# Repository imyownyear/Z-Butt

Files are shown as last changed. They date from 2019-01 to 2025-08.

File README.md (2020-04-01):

Licensed under: [Attribution-NonCommercial-ShareAlike 4.0 International (CC BY-NC-SA 4.0)](https://creativecommons.org/licenses/by-nc-sa/4.0/)

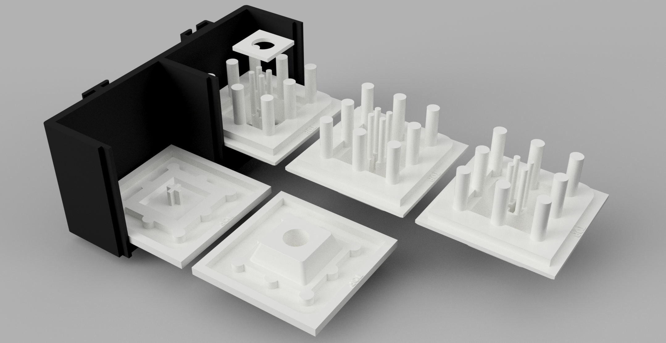
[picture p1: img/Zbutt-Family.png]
Z-Butt-1U Family


# Z-Butt
## An Artisan keycap creation platform.

If you have any questions, please contact me at:

Discord: Zappycobra#0001

[Discord Server ](https://discord.gg/nUsyadp)

Reddit: /u/imyownyear

Special thanks to yatara-cc, Fiscal_rascal, Cardiactuna, Davness<?>, CorruptedCaps, and morrae for helping with testing, providing resources, and feedback.

Please see the [Wiki](https://github.com/imyownyear/Z-Butt/wiki) for how to use, print, and make keycaps using ZButt.

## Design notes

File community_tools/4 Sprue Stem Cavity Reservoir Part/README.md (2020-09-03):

### Created by: deag
## Tool name: 4 Sprue Stem Cavity Reservoir Part
For use with:4 Sprue Stem Cavity

Sizing: 1U

Description:Pour silicone into stem cavity part 3/4 of the way up the sprue, attach the reservoir insert onto sprues. If needed, pour more silicone around insert for higher reservoir walls

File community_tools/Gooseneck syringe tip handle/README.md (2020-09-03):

### Created by: Dusty Caps
## Tool name: Gooseneck syringe tip handle
For use with: Luer slip tip syringe tips.

Sizing: NA

Description: A handle designed to be printed with an FDM printer, the tip is sized to accept luer slip tip syringe tips.

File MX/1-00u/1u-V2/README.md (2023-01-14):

Licensed under: [Attribution-NonCommercial-ShareAlike 4.0 International (CC BY-NC-SA 4.0)](https://creativecommons.org/licenses/by-nc-sa/4.0/)

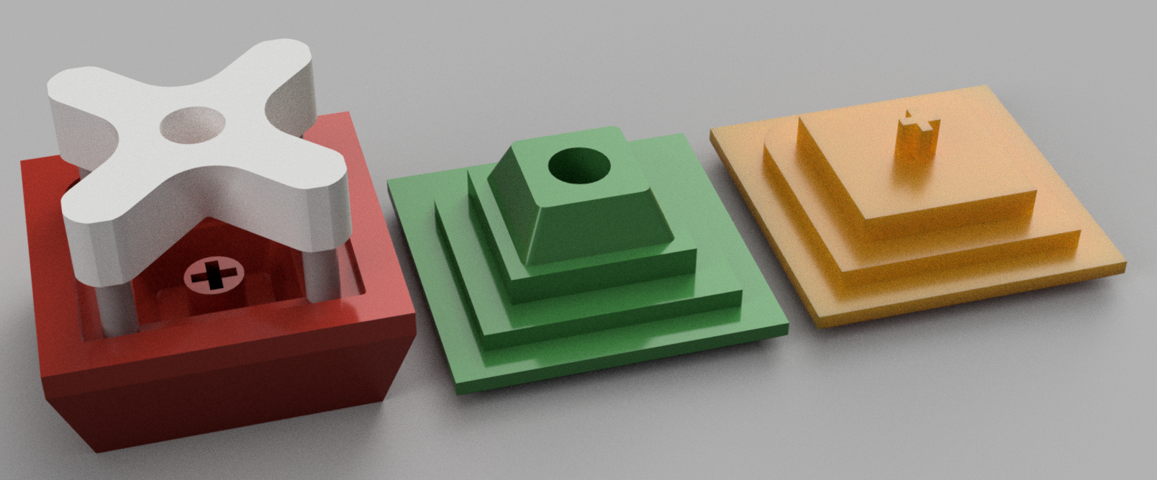
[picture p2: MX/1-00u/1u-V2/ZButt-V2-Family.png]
ZButt-1U V2 Family


# Z-Butt V2
## An Artisan keycap creation platform.

Please use 3mm Rods/Dowels with this version of Zbutt as the Sprues.

You can also glue on 5mmx1mm disc magnets to the bottom of the Master and Sculpting bases to use in combination with the Sculpting Helper.

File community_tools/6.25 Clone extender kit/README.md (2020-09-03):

### Created by: gooberpsycho
## Tool name: 6.25 Clone Riser Cavity
For use with:No Hassle Base or Lego 

Sizing: 6.25U

Description:Use in conjunction with two clone NoHassle's, one 6.25 Clone Extender, 
and one 6.25 Stem cavity in order to clone the 6.25 Stem Cavity in resin. Assemble the Clone No Hassle ends with the Clone Extender,
forming a box. Place Clone riser inside box, flush with bottom. Finally, place 6.25 stem cavity in box, on top of clone riser, 
flush with the riser's sides. Recommend placing clay inside riser to hold Stem Cavity in place so it doesn't move when pouring silicone. 
Pour enough silicone to completely cover stem cavity and allow to fully cure. You can then cast a new 6.25U Stem cavity out of resin.

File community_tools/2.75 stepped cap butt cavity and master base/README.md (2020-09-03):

### Created by: gooberpsycho
## Tool name: Stepped Caps Stem Cavity
For use with:No Hassle Base or Lego

Sizing:2.75u

Description:Use as normal 2.75U Stem Cavity. Two No Hassle Base end pieces, one No Hassle Extender 2 are needed.
Form a box using the No Hassle Base and Extender 2, then place Stepped Caps Stem Cavity into box, flush against bottom of box.
Pour Silicone in same manner as any other Stem Cavity, leaving a few millimeters of the sprues visible above the surface of the silicone. Used in conjunction with the Stepped Caps Master Base, Stepped Caps Lock key will be created.

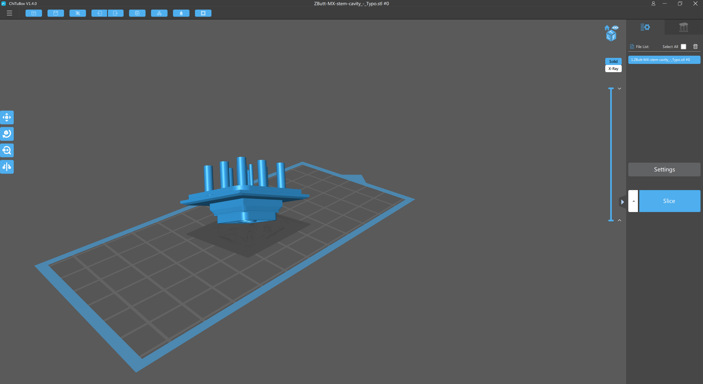
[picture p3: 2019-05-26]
img/angled-on-x-butt.png

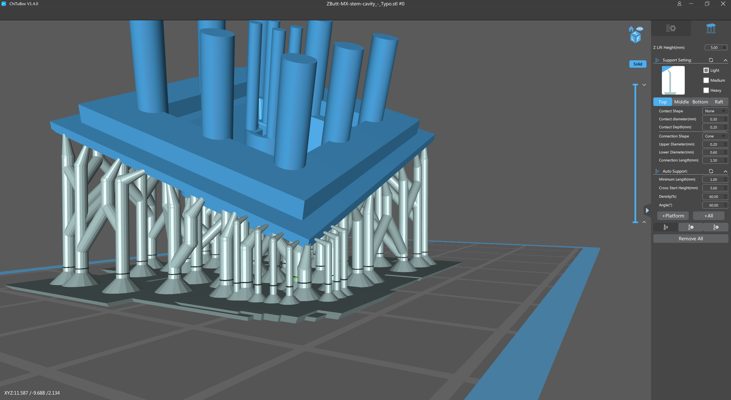
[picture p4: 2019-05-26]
img/light-support-reinforce-butt.png

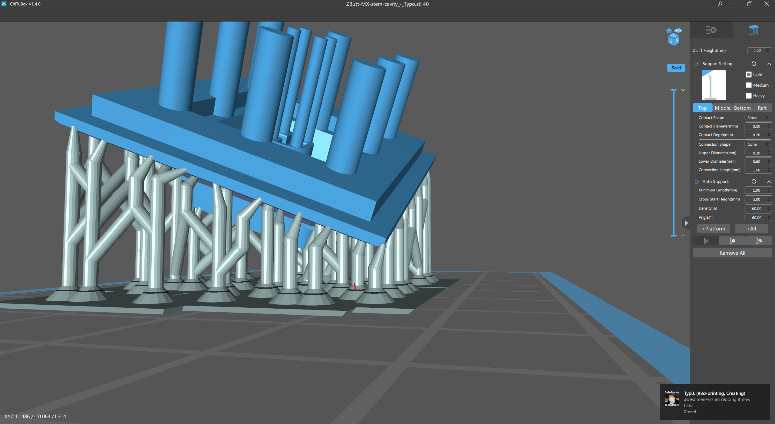
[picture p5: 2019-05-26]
img/heavy-supports-butt.png

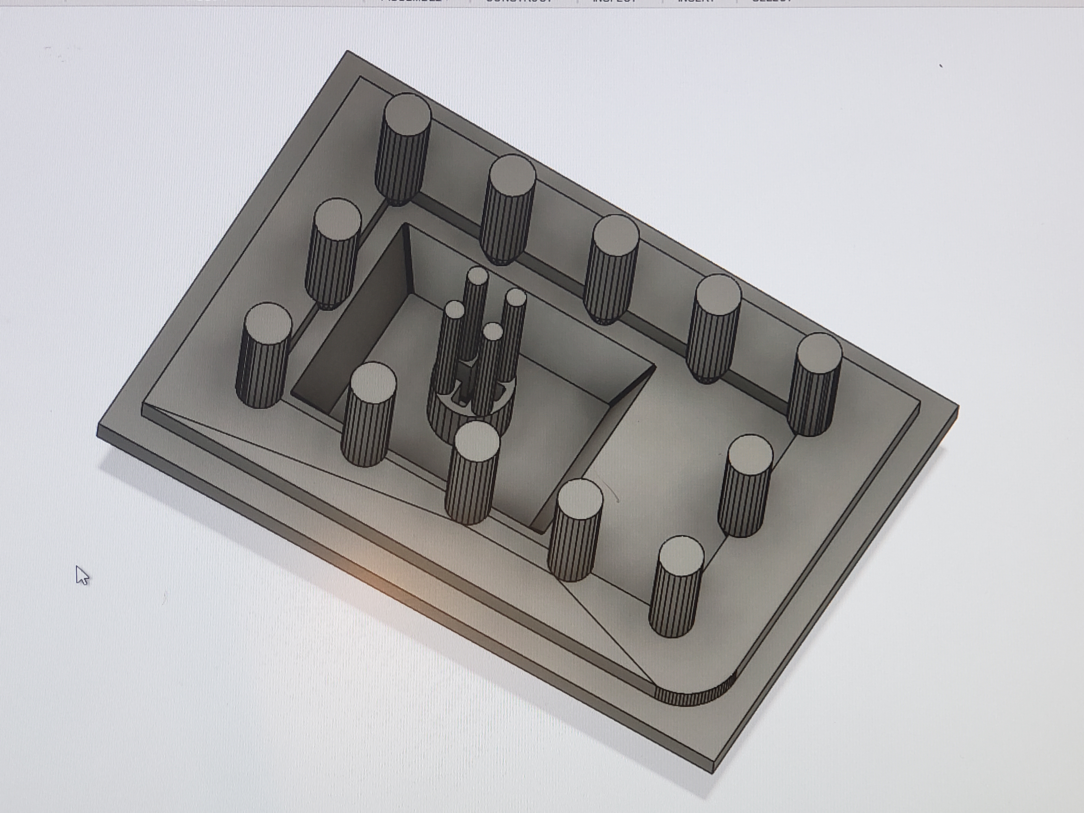
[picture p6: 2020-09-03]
community_tools/2.75 stepped cap butt cavity and master base/20200730_200228 - Robert Maynard.jpg

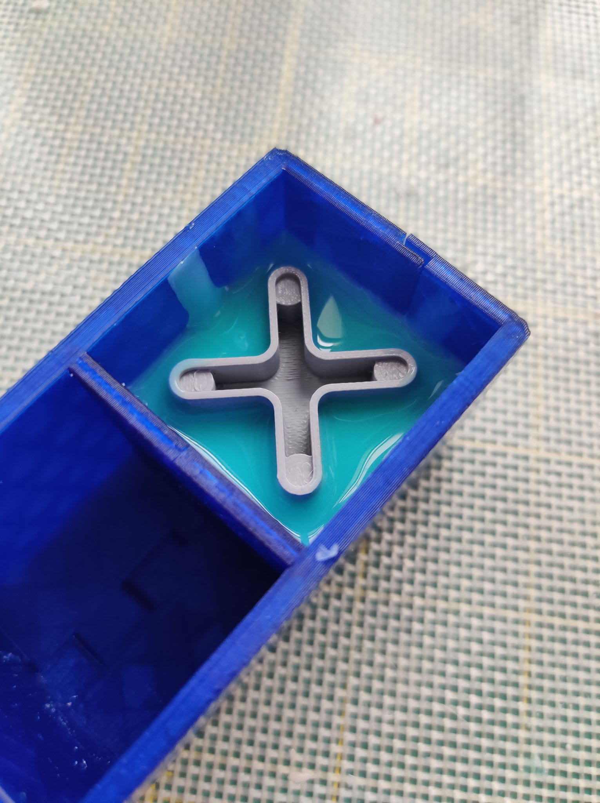
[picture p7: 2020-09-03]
community_tools/4 Sprue Stem Cavity Reservoir Part/118154245_2524324694526478_4820017302277932408_n - deagcaps.jpg

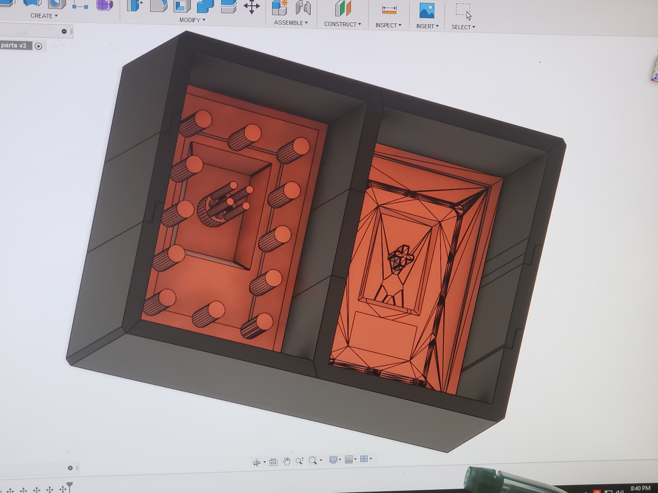
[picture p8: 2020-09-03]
community_tools/2.75 stepped cap butt cavity and master base/20200730_204056 - Robert Maynard.jpg

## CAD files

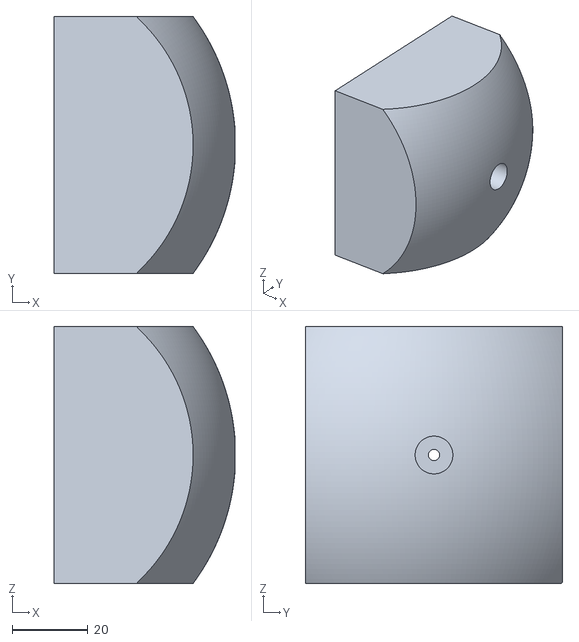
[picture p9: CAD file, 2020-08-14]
AngleHolder/AngleHolder_4x4_B.stl
47.8 x 68.0 x 68.0

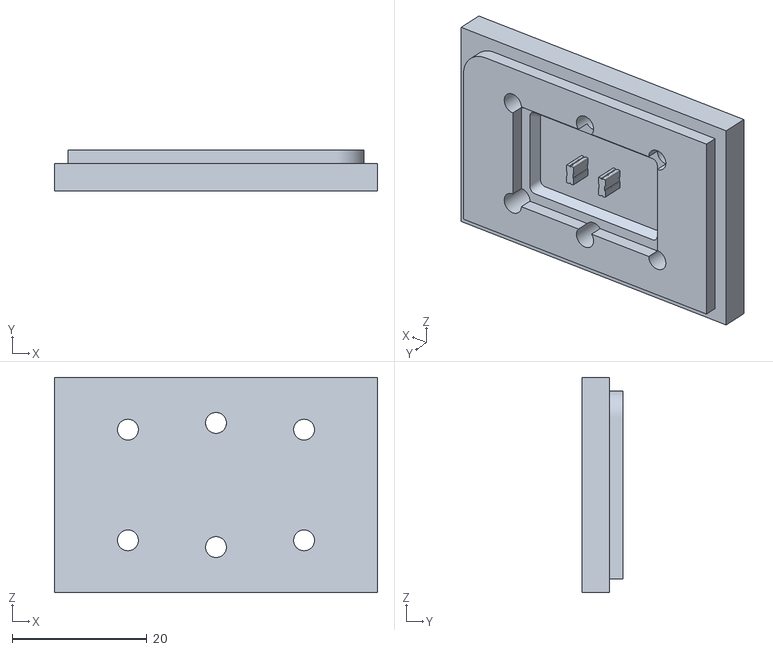
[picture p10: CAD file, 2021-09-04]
Choc/1.5U/Choc_1.5U_StemCavity.stl
48.0 x 6.10 x 32.0

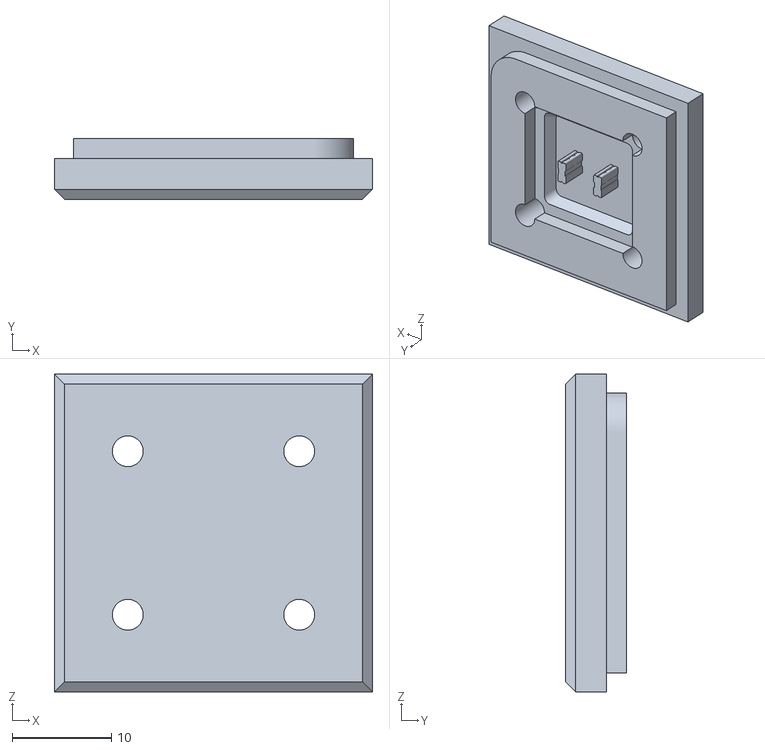
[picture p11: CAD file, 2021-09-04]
Choc/1U/Choc_1U_StemCavity.stl
32.0 x 6.10 x 32.0

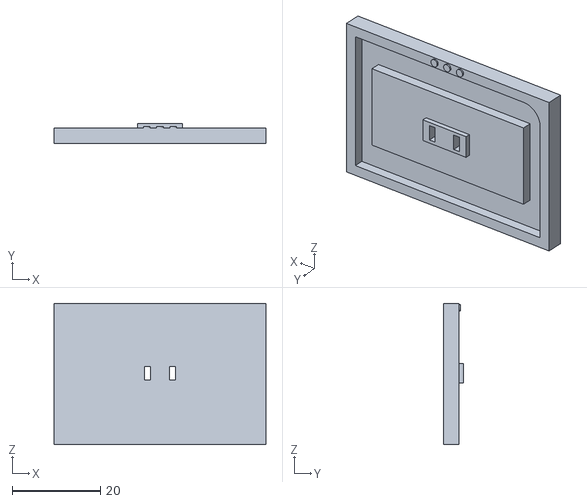
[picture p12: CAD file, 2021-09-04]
Choc/2U/Choc_2U_MasterBase.stl
48.0 x 4.50 x 32.0

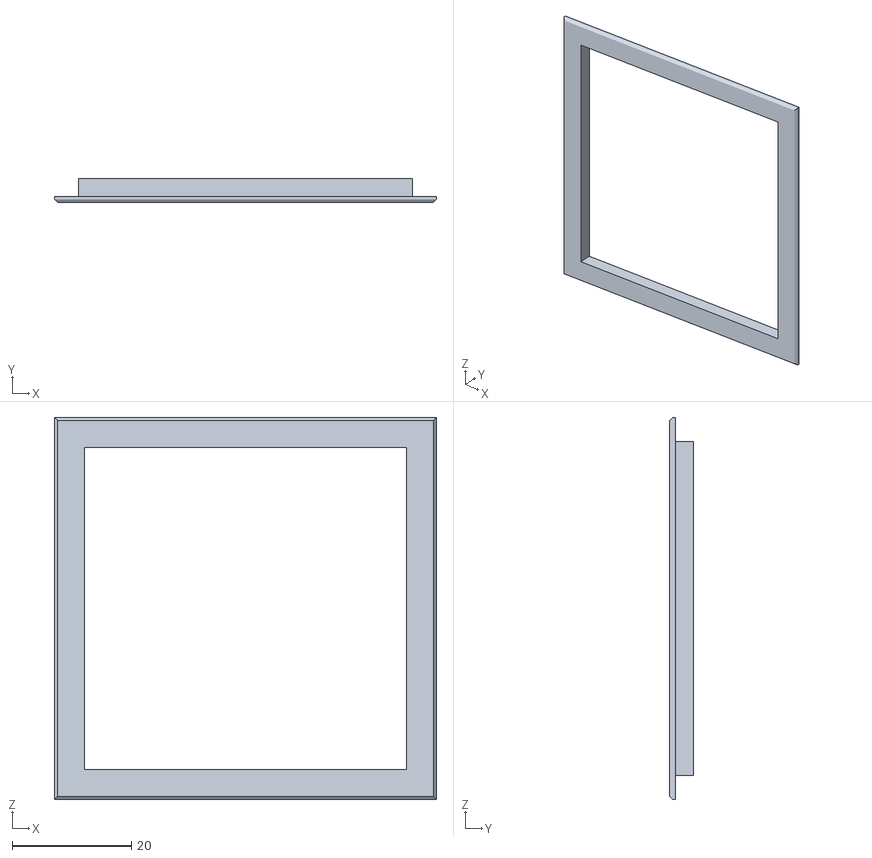
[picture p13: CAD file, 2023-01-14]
CloneRiser/1U/ZButt_2x2_CloneRiser_Master.stl
64.0 x 4.00 x 64.0

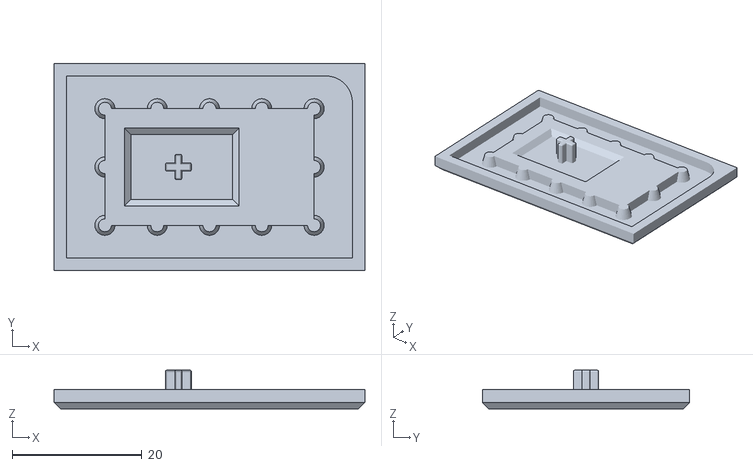
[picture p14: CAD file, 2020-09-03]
community_tools/2.75 stepped cap butt cavity and master base/Stepped Caps Master Base - Robert Maynard.stl
48.0 x 32.0 x 6.00

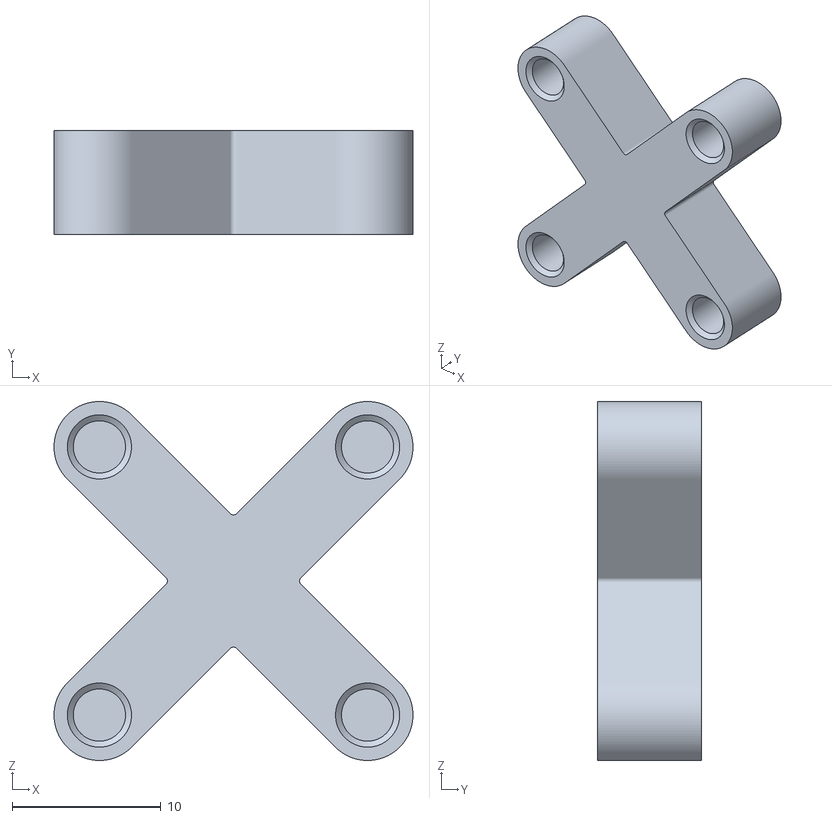
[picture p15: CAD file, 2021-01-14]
community_tools/4 Sprue Stem Cavity Reservoir Part/Stem Reservoir 4 Sprue - deagcaps - Edit.STL.stl
24.1 x 7.00 x 24.1

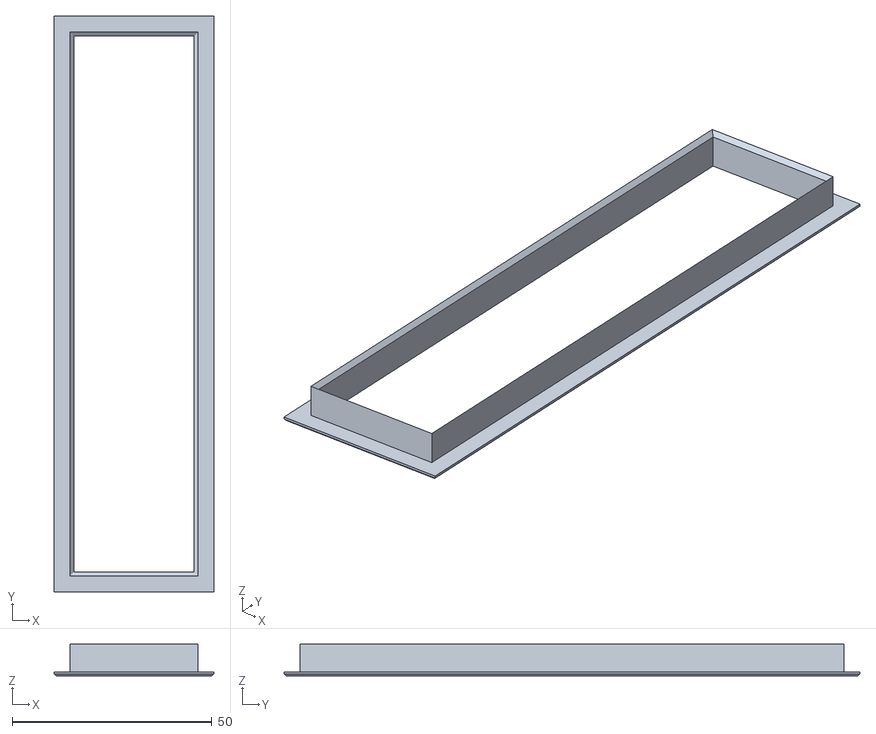
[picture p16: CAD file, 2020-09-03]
community_tools/6.25 Clone extender kit/6-25u Stem Cavity Clone Riser - Robert Maynard.stl
40.0 x 144.0 x 8.00

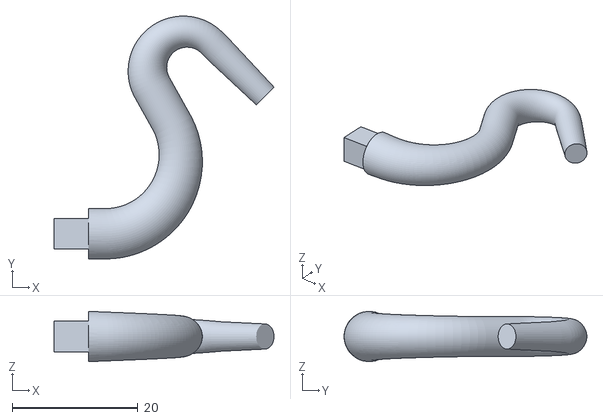
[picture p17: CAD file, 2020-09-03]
community_tools/Gooseneck syringe tip handle/gooseneck stem.STL
35.0 x 38.6 x 8.00

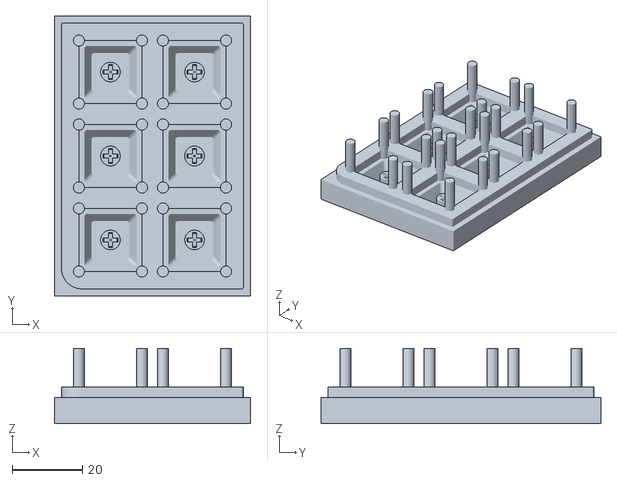
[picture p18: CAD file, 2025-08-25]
MX/1-00u/1u - Production/ZButt-StemCavity-2x3.stl
56.0 x 79.9 x 21.5

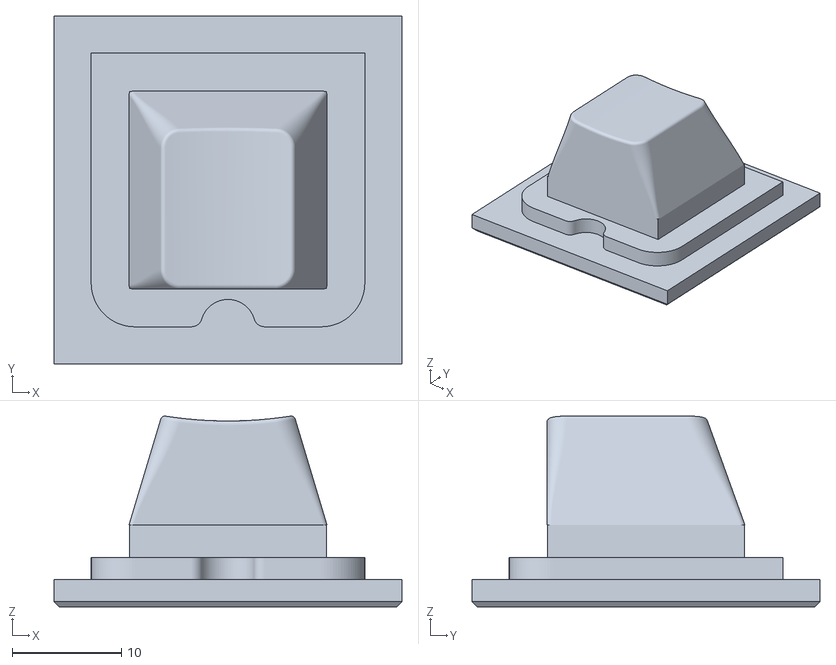
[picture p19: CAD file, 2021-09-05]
MX/1-00u/1u-V2/R1_CherryOnBase.stl
31.8 x 31.8 x 17.4

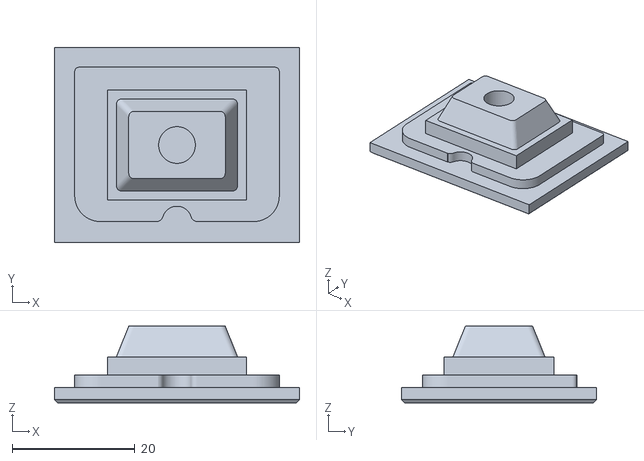
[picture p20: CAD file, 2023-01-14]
MX/1-25u/V2/SculptingBase.stl
40.0 x 31.8 x 12.5

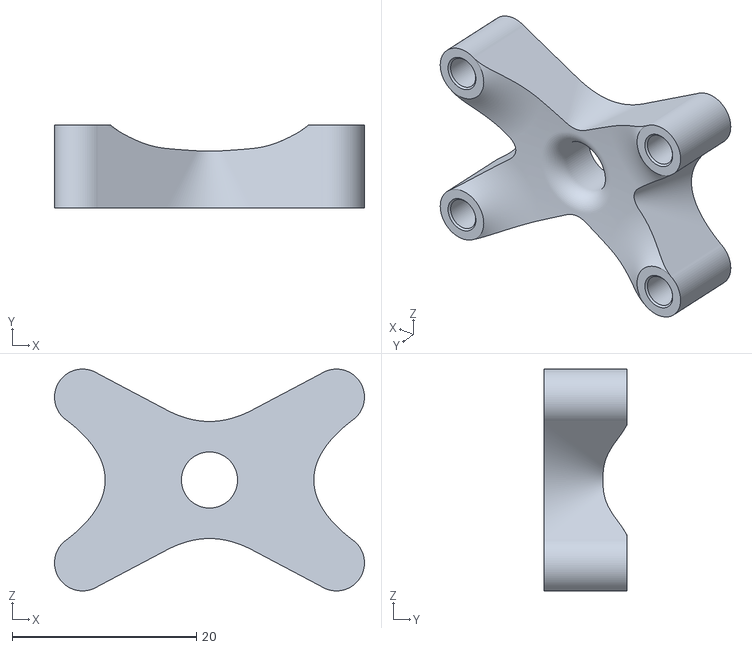
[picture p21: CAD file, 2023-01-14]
MX/1-50u/V2/Reservoir.stl
33.7 x 9.00 x 24.1

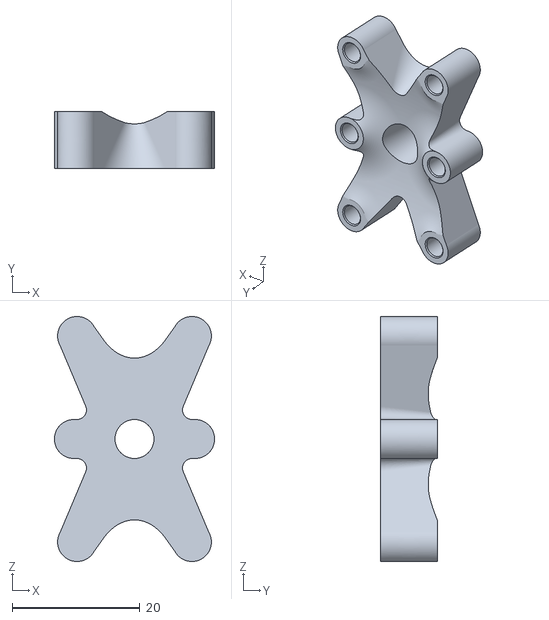
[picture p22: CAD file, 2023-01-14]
MX/1-75u/V2/Reservoir.stl
25.1 x 9.00 x 38.4

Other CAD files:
MX/10-00u/ZButt-MasterBase-10u.stl
MX/2-00u/V2/Reservoir.stl
MX/2-25u/V2/Reservoir.stl
MX/2-50u/ZButt_2-5U_StemCavity.stl
Alps/1-25u/ZButt_1-25U_MasterBase.stl
Alps/1-25u/ZButt_1-25U_SculptingBase.stl
Alps/1-25u/ZButt_1-25U_StemCavity.stl
Alps/1-5u/ZButt_1-5U_MasterBase.stl
Alps/1-5u/ZButt_1-5U_SculptingBase.stl
Alps/1-5u/ZButt_1-5U_StemCavity.stl
Alps/1-75u/ZButt_1-75U_MasterBase.stl
Alps/1-75u/ZButt_1-75U_SculptingBase.stl
Alps/1-75u/ZButt_1-75U_StemCavity.stl
Alps/1u/ZButt_1U_MasterBase.stl
Alps/1u/ZButt_1U_SculptingBase.stl
Alps/1u/ZButt_1U_StemCavity.stl
Alps/2-25u/ZButt_2-25U_MasterBase.stl
Alps/2-25u/ZButt_2-25U_SculptingBase.stl
Alps/2-25u/ZButt_2-25U_StemCavity.stl
Alps/2-5u/ZButt_2-5U_MasterBase.stl
Alps/2-5u/ZButt_2-5U_SculptingBase.stl
Alps/2-5u/ZButt_2-5U_StemCavity.stl
Alps/2-75u/ZButt_2-75U_MasterBase.stl
Alps/2-75u/ZButt_2-75U_SculptingBase.stl
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

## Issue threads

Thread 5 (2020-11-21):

Stem size to big when printing it with material jetting

locomain, 2020-11-21:
Not really sure if this ends up being a issue or just a question but i am wondering if SLA shrinkage is calculated into the cavity model?
When printing the part with material jetting (wich should be one of the most accurate printing techniques) the stem always ends up loose in the cast.

imyownyear, 2020-12-13:
You can use the .step file to modify the measurements to suite your printing needs.

Closed 2021-03-12.

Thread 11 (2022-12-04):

Can't find STL files for v2 Reservoirs

osboy12, 2022-12-04:
I see STL files for the bases and stem cavities, but not for the reservoirs, except for the 1U size.  Can we get .STL files for the reservoirs? Or are we meant to print and use multiple 1u reservoirs?

osboy12, 2022-12-04:
Just realized that only the 1u comes in V2.

Closed 2022-12-04.

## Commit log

2019-01-03 Renames STL files
    [ZButt-MX-1U-master-base v4.stl, ZButt-MX-1U-sculpting-base v4.stl, Zbutt-MX-1U-stem-cavity.stl]
2019-01-03 Add files via upload
    A 2U version of the Z-Butt system
    [Z-Butt-MX-2U-master-base.stl, Z-Butt-MX-2U-stem-cavity.stl]
2019-01-03 Delete Z-Butt-MX-2U-stem-cavity.stl
    stems were 1mm off
    [Z-Butt-MX-2U-stem-cavity.stl]
2019-01-08 Added folders and 1.5u files
    [2uSynth.stl, QuestCaps-ZButt-MX-1U-P1 v4.stl, Z-Butt-MX-1-5U-master-base.stl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]
2019-01-08 Added fixed 1.5u stem cavity
    [Z-Butt-MX-1-5U-stem-cavity.stl]
2019-01-08 Added 1.5u sculpting base
    [Z-Butt-MX-1-5U-sculpting-base.stl]
2019-01-08 Added 2u files
    [Z-Butt-MX-2U-master-base.stl, Z-Butt-MX-2U-sculpting-base.stl, Z-Butt-MX-2U-stem-cavity.stl]
2019-01-13 Added no hassle basses for 1.5u and 2u curtesy of morrae
    [ZButt-1U-Master-base.stl, Zbutt-1-5U-Master-base.stl, Zbutt-2U-Master-base.stl]
2019-01-15 Added master base
    [ZButt-MX-1U-Master-base.stl]
2019-01-15 fixed some naming issues on the no hassle containers
    [ZButt-1U-Master-base.stl, Zbutt-1-5U-NoHassleContainer.stl, Zbutt-1U-NoHassleContainer.stl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]
2019-01-19 Removed round registration on 1.5u zbutt
    [Z-Butt-MX-1-5U-master-base.stl, Z-Butt-MX-1-5U-sculpting-base.stl, Z-Butt-MX-1-5U-stem-cavity.stl]
2019-01-19 Added fusion and step files
    [No-hassle-containers-1u.step, Zbutt-1-5u-stem-cavity.f3d, Zbutt-1-5u-stem-cavity.step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]
2019-06-07 Total overhaul of ZButt
    [Z-Butt-MX-1-5U-master-base.stl, Z-Butt-MX-1-5U-sculpting-base.stl, Z-Butt-MX-1-5U-stem-cavity.stl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]
2019-06-07 New No Hassle container added to 1U folder
    [ZButt_1U_NoHassle.stl]
2019-06-20 Fixed stab placement on 2u and 2.25u
    [ZButt_2-25U_MasterBase.stl, ZButt_2-25U_SculptingBase.stl, ZButt_2-25U_StemCavity.stl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]
2019-06-22 Added sizes 2.5, 2.75, 3, 4, 5, 6, 6.25, 7
    [ZButt_1-25U_MasterBase.stl, ZButt_1-25U_SculptingBase.stl, ZButt_1-25U_StemCavity.stl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]
2019-06-23 Added 1u NoHassle container
    [1U-No-Hassle.stl]
2019-07-23 Added 1u-2.75u of Alps and Topre
    [ZButt_1-25U_MasterBase.stl, ZButt_1-25U_SculptingBase.stl, ZButt_1-25U_StemCavity.stl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]
2019-07-23 Added ISO-ENTER
    [ZButt_ISO-ENTER_MasterBase-.stl, ZButt_ISO-ENTER_SculptingBase-.stl, ZButt_ISO-ENTER_StemCavity-.stl]
2019-08-04 Added TMX stem cavity in 1u
    [ZButt-StemCavity.stl]
2019-08-20 Changed names of the stl's
    Had the old naming convention in place. Added the new naming convention.
2019-08-20 Added 1U clone risers.
    [ZButt_1U_CloneRiser_Cavity.stl, ZButt_1U_CloneRiser_Master.stl]
2019-09-06 1u Stem Cavity .STEP added
    [ZButt_1U_StemCavity.step]
2019-09-15 Added experimental Modular ZButt
    [ZButt_1U_ModularStems.stl, ZButt_1U_StemCavity.stl]
2020-04-01 Added additional NoHassle tooling
    [NoHassle-Extender#1.stl, NoHassle-Extender#2.stl, NoHassle-Extender#3.stl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]
2020-05-11 fixed 6.25u stem positions
    [ZButt-MasterBase-6.25u.stl, ZButt-StemCavity-6.25u-Sprue.stl, ZButt_6-25U_MasterBase.stl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]
2020-08-12 Add 1x1U angle holder.
    [AngleHolder_1x1U.stl]
2020-08-14 Added 4x4 AngleHolder
    [AngleHolder_4x4_A.stl, AngleHolder_4x4_B.stl]
2020-11-21 Added 2x2 and 2x5 production tooling to the 1u filder for MX tooling
    [NoHassle2x5Extend.stl, ZButt-MasterBase-2x2.stl, ZButt-MasterBase-2x5.stl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]
2021-01-14 Added 1u Master and Sculpting without sprues.
    [Stem Reservoir 4 Sprue - deagcaps - Edit.STL.stl, ZButt_1U_MasterBase_NoSprue.stl, ZButt_1U_SculptingBase_NoSprue.stl]
2021-03-12 Added Zbutt V2 in the 1u variety
    [1u-Resevoir-Topper-0.3.stl, MasterBase.stl, Sculpting-Helper-Plus-p1.stl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]
2021-03-12 Added Stem Cavity STEP file
    [StemCavity.step]
2021-06-11 Fixed 2x2 measurements
    [ZButt-MasterBase-2x5.stl, ZButt-StemCavity-2x2-Recessed.stl, ZButt-StemCavity-2x2.stl]
2021-09-03 Adding 6.5u tools
    [SA-6.5u-OnMasterBase.stl, ZButt-MasterBase-6.5u.stl, ZButt-StemCavity-6.5u.stl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]
2021-09-04 Adding v1 1u NoSprue versions
    [ZButt_1U_StemCavity_NOSPRUE.stl, ZButt_1U_StemCavity_NOSPRUE_RECESSED.stl]
2021-09-04 Adding Choc Zbutt tools sizes 1U, 1.5U, and 2U
    [Choc_1.5U_MasterBase.stl, Choc_1.5U_SculptingBase.stl, Choc_1.5U_StemCavity.stl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]
2021-09-04 Moved 1u V1 tooling into its own directory: 1u-V1
    [ZButt_1U_MasterBase.stl, ZButt_1U_MasterBase_NoSprue.stl, ZButt_1U_SculptingBase.stl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]
2021-09-04 10U Meme tooling added
    [ZButt-MasterBase-10u.stl, ZButt-StemCavity-10u-Sprue.stl, Zbutt-SculptingBase-10u.stl]
2021-09-05 Addeed Cherry R1 to both v1 and v2
    [R1_CherryOnBase.stl, ZButt_R1_CherryOnBase.stl]
2021-11-26 2x3 production tooling)
    [ZButt-MasterBase-2x3 .stl, ZButt-StemCavity-2x3-Recessed.stl, ZButt-StemCavity-2x3.stl]
2021-12-05 2x3 No Hassle Extender (#8)
    [NoHassle2x3Extend.stl]
2022-08-07 Added topre-v2 stem cavity
    1. Created v1 and v2 folder for topre
    2. Added older filed to v1
    3. Added stem cavity to v2
    [StemCavity.stl, ZButt_1U_MasterBase.stl, ZButt_1U_SculptingBase.stl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]
2023-01-14 Adding more sizes to v2 and reorganize
    [1u-Resevoir-Topper-0.3.stl, MasterBase.stl, NoHassle2x5Extend.stl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]
2023-01-14 Moving prod 2x3
    [NoHassle2x3Extend.stl, ZButt-MasterBase-2x3 .stl, ZButt-StemCavity-2x3-Recessed.stl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]
2025-08-25 Update ZButt-StemCavity-2x3.STL
    Existing model was incorrectly made, merging in edited version.
    [ZButt-StemCavity-2x3.stl]
